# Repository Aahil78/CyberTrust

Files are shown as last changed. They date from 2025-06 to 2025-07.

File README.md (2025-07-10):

# CyberTrust
CyberTrust Is A RP2350A Based Security Key, it can be used as a FIDO2 Secure Key for secure authentication and account safety.

Features:
- Custom PCB
- Custom Enclosure
- Based on the RP2350A MCU
- WS2812B RGB LED
- User Presence Button
- USB-A Male Port
- OSH and OSS

## Images
### PCB




### Schematic


### Enclosure/Assembly



## Bill Of Materials

| Comment | Designator | Footprint | LCSC Part # | Quantity | Total Price |
|---|---|---|---|---|---|
| RP2350_60QFN | U1 | RP2350-QFN-60-1EP_7x7_P0.4mm_EP3.4x3.4mm_ThermalVias| C42411118 | 1 | $ 1.65 |
| 4.7u | C10, C6, C7, C9 | 0402 | C23733 | 4 | $ 0.26 |
| 15p | C3, C4 | 0402 | C1548 | 2 | $ 0.1 |
| 33 | R5 | 0402 | C25105 | 1 | $ 0.06 |
| USB3_A | J1 | USB3_A_Plug_Wuerth_692112030100_Horizontal | C7527682 | 1 | $ 0.44 |
| WS2812B | D1 | LED_WS2812B_PLCC4_5.0x5.0mm_P3.2mm | C2761795 | 1 | $ 0.41 |
| 1k | R2, R4, R6 | 0402 | C11702 | 3 | $ 0.06 |
| NCP1117-3.3_SOT223| U2 | SOT-223-3_TabPin2 | C26537 | 1 | $ 1.31 |
| 3.3u | L1 | L_pol_2016 | C42411119 | 1 | $ 1.29 |
| 0 | R10 | 0402 | C17168 | 1 | $ 0.06 |
| W25Q128JVS | U3 | SOIC-8_5.23x5.23mm_P1.27mm | C97521 | 1 | $ 0.76 |
| SW_Push | SW3 | SW_Push_SPST_NO_Alps_SKRK | C115357 | 1 | $ 0.63 |
| 330Ω | R3 | 0805 | C17630 | 1 | $ 0.19 |
| 10u | C1, C19, C5 | 0805 | C15850 | 3 | $ 0.22 |
| 100n | C11, C12, C13, C14, C15, C16, C17, C18, C2, C8 | 0402 | C1525 | 10 | $ 0.12 |
| SW_Push | SW1, SW2 | SW_Push_1P1T_NO_Vertical_Wuerth_434133025816 | C5504987 | 2 | $ 1.86 |
| ABM8-272-T3 | Y1 | Crystal_SMD_3225-4Pin_3.2x2.5mm | C20625731 | 1 | $ 0.37 |
| 27 | R7, R8 | 0402 | C25100 | 2 | $ 0.06 |

## Additional Stuff
- PCB - $4.2
- Enclosure (3D Printed Case and Top) - Bottom: $10.89, Top(Transparent Resin): $14.40
- Screws - $0.132
- PCBA Costs - $60.66 (I need to solder RGBs, MOQ: 5, Total Cost: $0.41)

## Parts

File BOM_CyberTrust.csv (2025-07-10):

Comment | Designator | Footprint | LCSC Part # | Quantity | Total Price
RP2350_60QFN | U1 | RP2350-QFN-60-1EP_7x7_P0.4mm_EP3.4x3.4mm_ThermalVias | C42411118 | 1 | $1.65
4.7u | C10, C6, C7, C9 | 402 | C23733 | 4 | $0.26
15p | C3, C4 | 402 | C1548 | 2 | $0.10
33 | R5 | 402 | C25105 | 1 | $0.06
USB3_A | J1 | USB3_A_Plug_Wuerth_692112030100_Horizontal | C7527682 | 1 | $0.44
WS2812B | D1 | LED_WS2812B_PLCC4_5.0x5.0mm_P3.2mm | C2761795 | 1 | $0.41
1k | R2, R4, R6 | 402 | C11702 | 3 | $0.06
NCP1117-3.3_SOT223 | U2 | SOT-223-3_TabPin2 | C26537 | 1 | $1.31
3.3u | L1 | L_pol_2016 | C42411119 | 1 | $1.29
0 | R10 | 402 | C17168 | 1 | $0.06
W25Q128JVS | U3 | SOIC-8_5.23x5.23mm_P1.27mm | C97521 | 1 | $0.76
SW_Push | SW3 | SW_Push_SPST_NO_Alps_SKRK | C115357 | 1 | $0.63
330Ω | R3 | 805 | C17630 | 1 | $0.19
10u | C1, C19, C5 | 805 | C15850 | 3 | $0.22
100n | C11, C12, C13, C14, C15, C16, C17, C18, C2, C8 | 402 | C1525 | 10 | $0.12
SW_Push | SW1, SW2 | SW_Push_1P1T_NO_Vertical_Wuerth_434133025816 | C5504987 | 2 | $1.86
ABM8-272-T3 | Y1 | Crystal_SMD_3225-4Pin_3.2x2.5mm | C20625731 | 1 | $0.37
27 | R7, R8 | 402 | C25100 | 2 | $0.06
Additonal Stuff:
PCB - $4.2
Enclosure (3D Printed Case and Top) - Bottom: $10.89, Top(Transparent Resin): $14.40
Screws - $0.132
PCBA Costs - $60.66 (I need to solder RGBs, MOQ: 5, Total Cost: $0.41)

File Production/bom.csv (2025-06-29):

Designator | Footprint | Quantity | Value | LCSC Part #
C1, C19, C5 | 0805 | 3 | 10u
C10, C6, C7, C9 | 0402 | 4 | 4.7u
C11, C12, C13, C14, C15, C16, C17, C18, C2, C8 | 0402 | 10 | 100n
C3, C4 | 0402 | 2 | 15p
D1 | LED_WS2812B_PLCC4_5.0x5.0mm_P3.2mm | 1 | WS2812B
H1, H2, H3, H4 | MountingHole_2.7mm_M2.5 | 4 | MountingHole
J1 | USB3_A_Plug_Wuerth_692112030100_Horizontal | 1 | USB3_A
L1 | L_pol_2016 | 1 | 3.3u
R1, R9 | 0402 | 2 | DNF
R10 | 0402 | 1 | 0
R2, R4, R6 | 0402 | 3 | 1k
R3 | 0805 | 1 | 330Ω
R5 | 0402 | 1 | 33
R7, R8 | 0402 | 2 | 27
SW1, SW2 | SW_Push_1P1T_NO_Vertical_Wuerth_434133025816 | 2 | SW_Push
SW3 | SW_Push_SPST_NO_Alps_SKRK | 1 | SW_Push
U1 | RP2350-QFN-60-1EP_7x7_P0.4mm_EP3.4x3.4mm_ThermalVias | 1 | RP2350_60QFN
U2 | SOT-223-3_TabPin2 | 1 | NCP1117-3.3_SOT223
U3 | SOIC-8_5.23x5.23mm_P1.27mm | 1 | W25Q128JVS
Y1 | Crystal_SMD_3225-4Pin_3.2x2.5mm | 1 | ABM8-272-T3

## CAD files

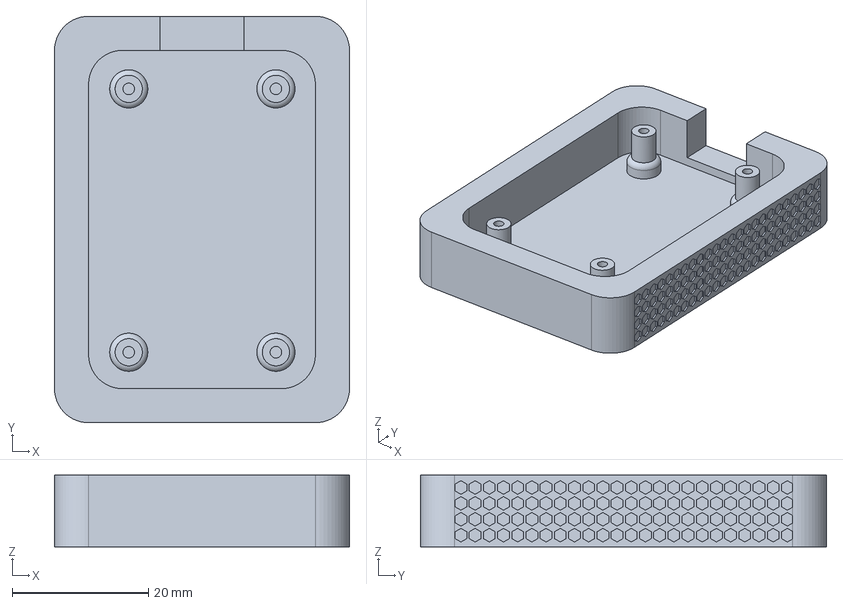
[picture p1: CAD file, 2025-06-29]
3D Models/Bottom.step
43.3 x 59.7 x 10.5 mm

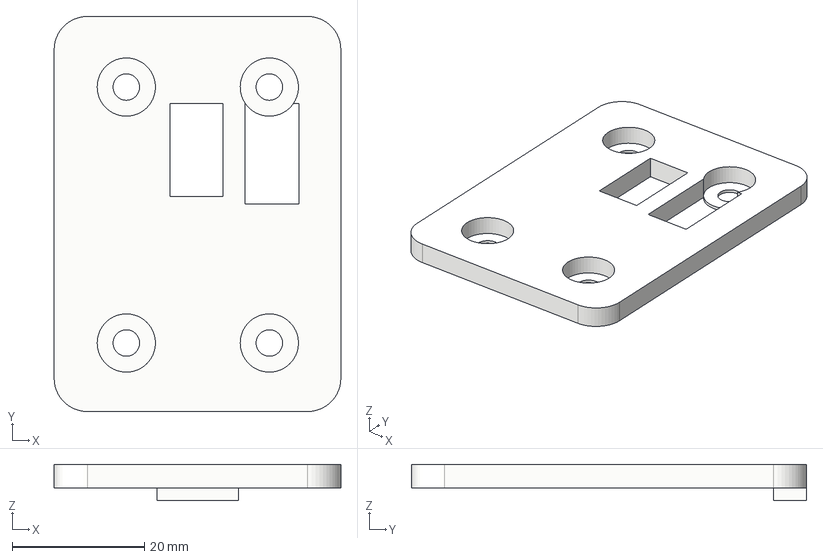
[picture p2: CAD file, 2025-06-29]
3D Models/Top.step
43.3 x 59.7 x 5.50 mm

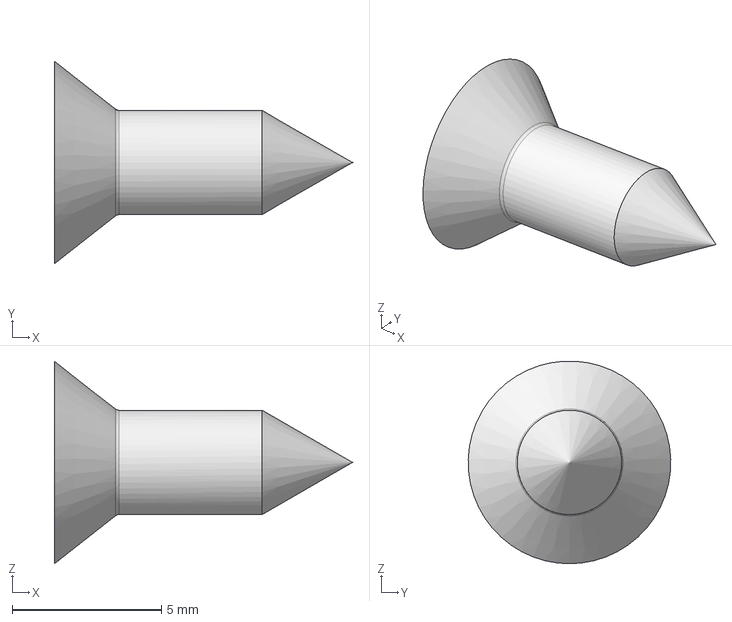
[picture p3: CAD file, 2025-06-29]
3D Models/Screws.step
10.0 x 6.80 x 6.79 mm

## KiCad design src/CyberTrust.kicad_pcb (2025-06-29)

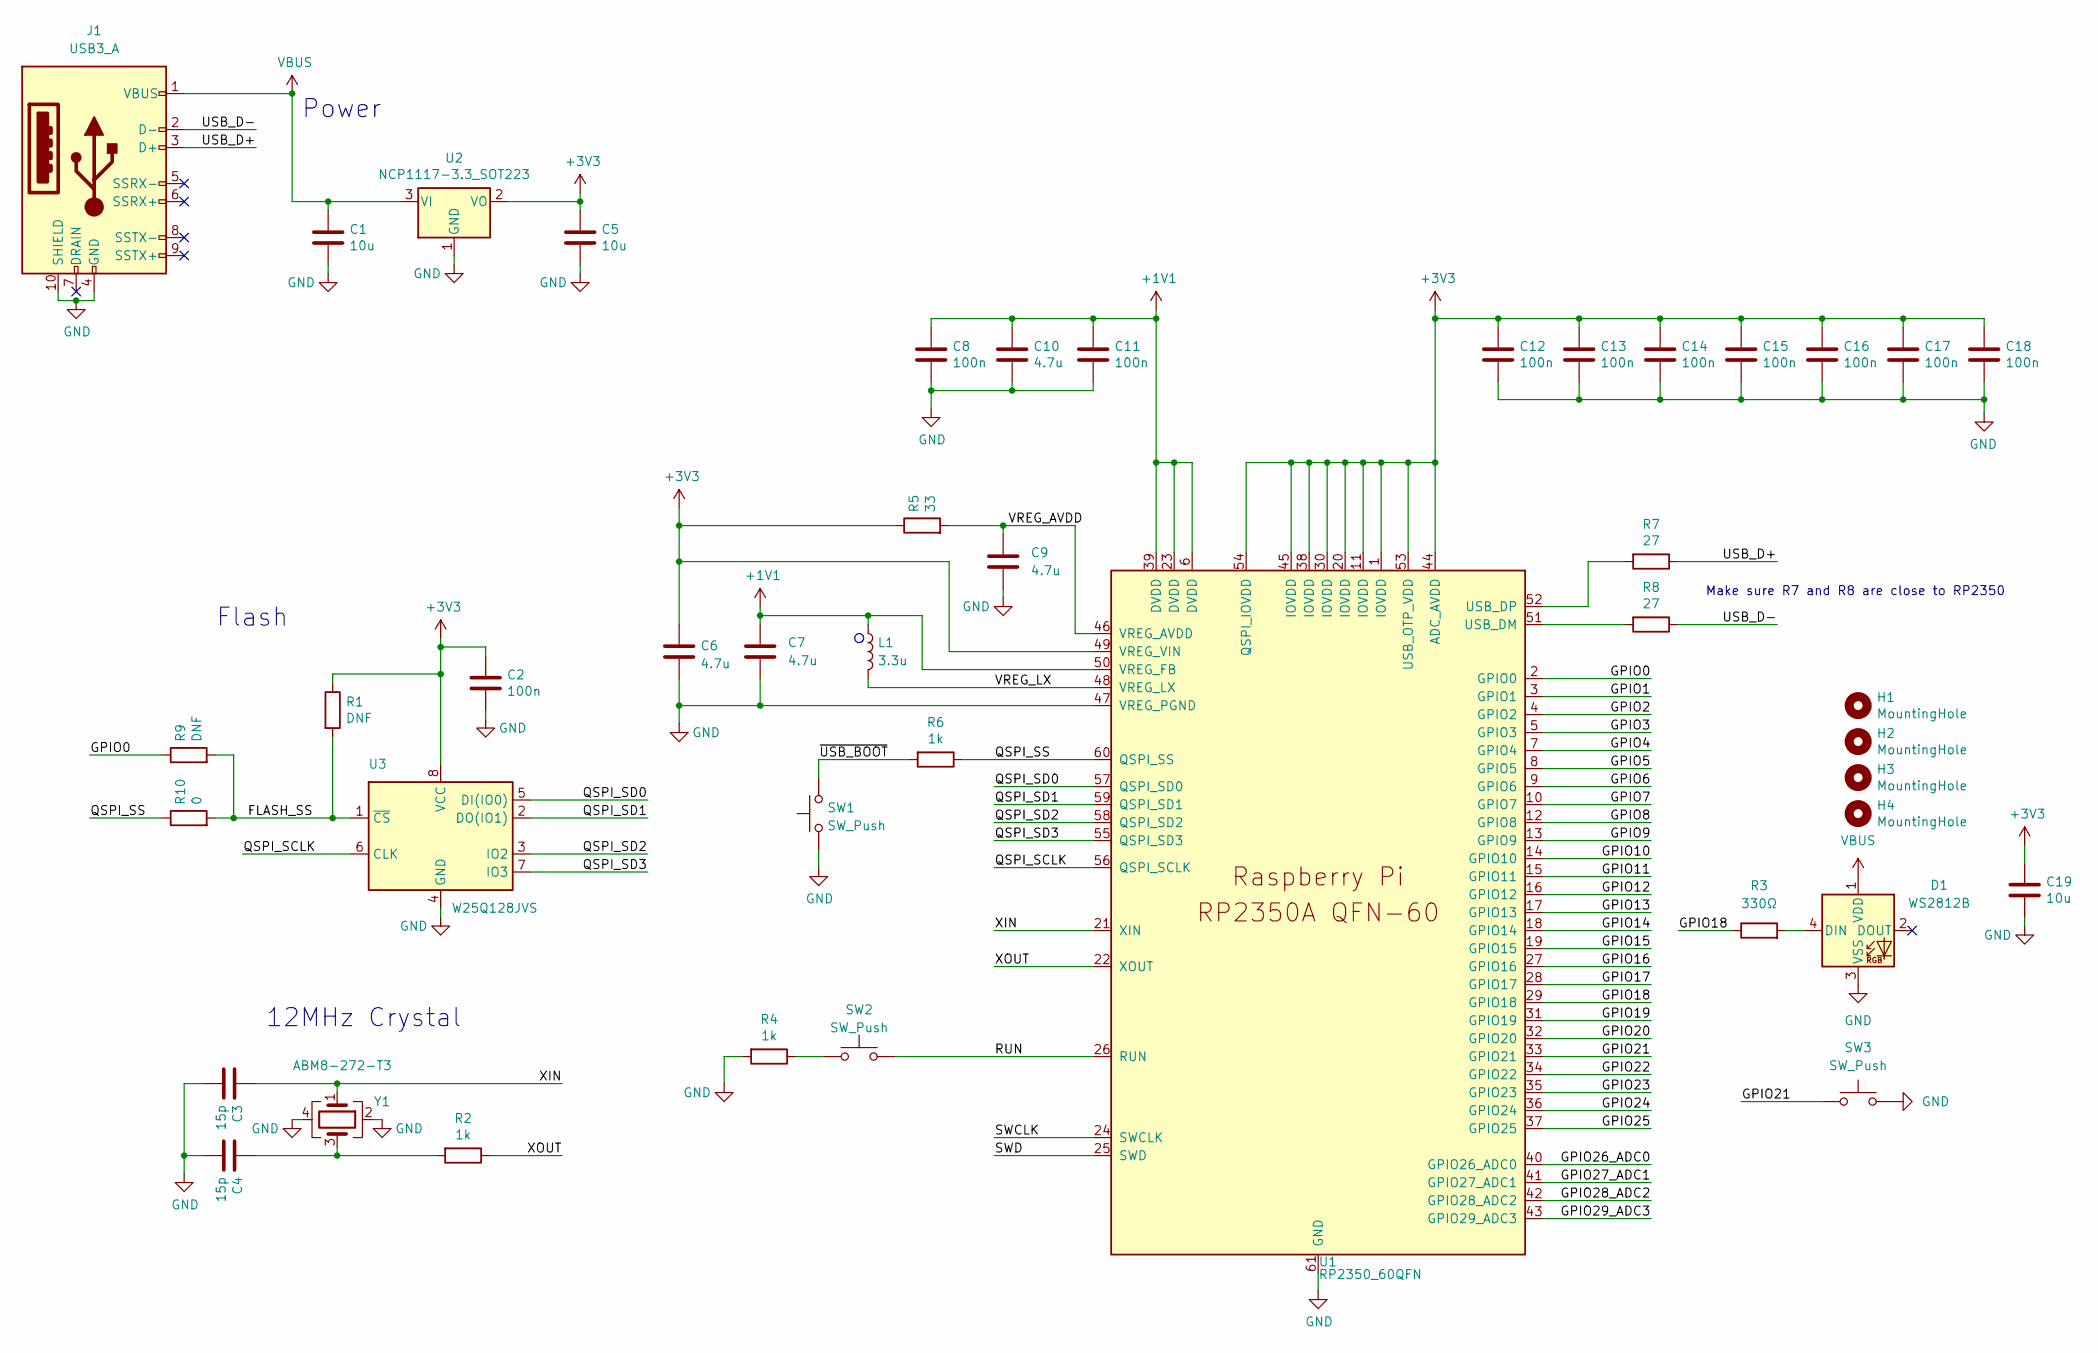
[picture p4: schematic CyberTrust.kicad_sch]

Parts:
C1, C5, C19: 10u; C_0805_2012Metric
C2, C8, C11, C12, C13, C14, C15, C16, C17, C18: 100n; C_0402_1005Metric
C3, C4: 15p; C_0402_1005Metric
C6, C7: 4.7u; C_0402_1005Metric_small_pads
C9, C10: 4.7u; C_0402_1005Metric
D1: WS2812B; LED_WS2812B_PLCC4_5.0x5.0mm_P3.2mm
H1, H2, H3, H4: MountingHole; MountingHole_2.7mm_M2.5
J1: USB3_A; USB3_A_Plug_Wuerth_692112030100_Horizontal
L1: 3.3u; L_pol_2016
R1, R9: DNF; R_0402_1005Metric
R2, R4, R6: 1k; R_0402_1005Metric
R3: 330Ω; R_0805_2012Metric_Pad1.20x1.40mm_HandSolder
R5: 33; R_0402_1005Metric
R7, R8: 27; R_0402_1005Metric
R10: 0; R_0402_1005Metric
SW1, SW2: SW_Push; SW_Push_1P1T_NO_Vertical_Wuerth_434133025816
SW3: SW_Push; SW_Push_SPST_NO_Alps_SKRK
U1: RP2350_60QFN; RP2350-QFN-60-1EP_7x7_P0.4mm_EP3.4x3.4mm_ThermalVias
U2: NCP1117-3.3_SOT223; SOT-223-3_TabPin2
U3: W25Q128JVS; SOIC-8_5.23x5.23mm_P1.27mm
Y1: ABM8-272-T3; Crystal_SMD_3225-4Pin_3.2x2.5mm

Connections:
+1V1: C7.1, C8.1, C10.1, C11.1, L1.1, U1.6 (DVDD), U1.23 (DVDD), U1.39 (DVDD), U1.50 (VREG_FB)
+3V3: C2.1, C5.1, C6.1, C12.1, C13.1, C14.1, C15.1, C16.1, C17.1, C18.1, C19.1, R1.1, R5.1, U1.1 (IOVDD), U1.11 (IOVDD), U1.20 (IOVDD), U1.30 (IOVDD), U1.38 (IOVDD), U1.44 (ADC_AVDD), U1.45 (IOVDD), U1.49 (VREG_VIN), U1.53 (USB_OTP_VDD), U1.54 (QSPI_IOVDD), U2.2 (VO), U3.8 (VCC)
/FLASH_SS: R1.2, R9.2, R10.2, U3.1 (~CS)
/GPIO0: R9.1, U1.2 (GPIO0)
/GPIO1: U1.3 (GPIO1)
/GPIO2: U1.4 (GPIO2)
/GPIO3: U1.5 (GPIO3)
/GPIO4: U1.7 (GPIO4)
/GPIO5: U1.8 (GPIO5)
/GPIO6: U1.9 (GPIO6)
/GPIO7: U1.10 (GPIO7)
/GPIO8: U1.12 (GPIO8)
/GPIO9: U1.13 (GPIO9)
/GPIO10: U1.14 (GPIO10)
/GPIO11: U1.15 (GPIO11)
/GPIO12: U1.16 (GPIO12)
/GPIO13: U1.17 (GPIO13)
/GPIO14: U1.18 (GPIO14)
/GPIO15: U1.19 (GPIO15)
/GPIO16: U1.27 (GPIO16)
/GPIO17: U1.28 (GPIO17)
/GPIO18: R3.1, U1.29 (GPIO18)
/GPIO19: U1.31 (GPIO19)
/GPIO20: U1.32 (GPIO20)
/GPIO21: SW3.1, U1.33 (GPIO21)
/GPIO22: U1.34 (GPIO22)
/GPIO23: U1.35 (GPIO23)
/GPIO24: U1.36 (GPIO24)
/GPIO25: U1.37 (GPIO25)
/GPIO26_ADC0: U1.40 (GPIO26_ADC0)
/GPIO27_ADC1: U1.41 (GPIO27_ADC1)
/GPIO28_ADC2: U1.42 (GPIO28_ADC2)
/GPIO29_ADC3: U1.43 (GPIO29_ADC3)
/QSPI_SCLK: U1.56 (QSPI_SCLK), U3.6 (CLK)
/QSPI_SD0: U1.57 (QSPI_SD0), U3.5 (DI(IO0))
/QSPI_SD1: U1.59 (QSPI_SD1), U3.2 (DO(IO1))
/QSPI_SD2: U1.58 (QSPI_SD2), U3.3 (IO2)
/QSPI_SD3: U1.55 (QSPI_SD3), U3.7 (IO3)
/QSPI_SS: R6.1, R10.1, U1.60 (QSPI_SS)
/RUN: SW2.2, U1.26 (RUN)
/SWCLK: U1.24 (SWCLK)
/SWD: U1.25 (SWD)
/USB_D+: J1.3 (D+), R7.1
/USB_D-: J1.2 (D-), R8.1
/VREG_AVDD: C9.1, R5.2, U1.46 (VREG_AVDD)
/VREG_LX: L1.2, U1.48 (VREG_LX)
/XIN: C3.1, U1.21 (XIN), Y1.1
/XOUT: R2.1, U1.22 (XOUT)
/~USB_BOOT: R6.2, SW1.2
GND: C1.2, C2.2, C3.2, C4.2, C5.2, C6.2, C7.2, C8.2, C9.2, C10.2, C11.2, C12.2, C13.2, C14.2, C15.2, C16.2, C17.2, C18.2, C19.2, D1.3 (VSS), J1.4 (GND), J1.10 (SHIELD), R4.2, SW1.1, SW3.2, U1.47 (VREG_PGND), U1.61 (GND), U2.1 (GND), U3.4 (GND), Y1.2, Y1.4
unnamed: C4.1, R2.2, Y1.3
unnamed: D1.4 (DIN), R3.2
unnamed: R4.1, SW2.1
unnamed: R8.2, U1.51 (USB_DM)
unnamed: R7.2, U1.52 (USB_DP)
VBUS: C1.1, D1.1 (VDD), J1.1 (VBUS), U2.3 (VI)

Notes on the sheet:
Flash
Make sure R7 and R8 are close to RP2350
12MHz Crystal
Power

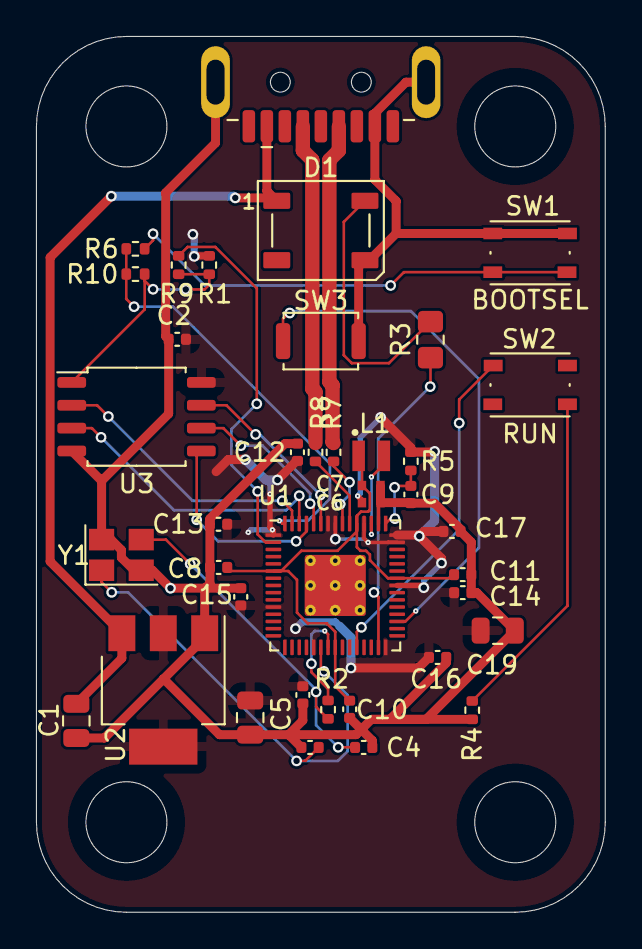
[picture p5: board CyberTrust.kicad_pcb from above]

Board: 2 copper layers, 31.6 x 48.7 mm, 43 parts (0 on the bottom side), 27 nets.

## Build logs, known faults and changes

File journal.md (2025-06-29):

---
title: "CyberTrust"
author: "Aahil"
description: "A RP2350A Based Hardware Security Key with a keypad add-on, RGB LED, and idk other things!"
created_at: "2025-06-25"
---

**Total time worked for designing: 80 hours**

## June 25th: Research, Schematic, and PCB Layout
Hi! I'm back with a new project, while my keyboard is being reviewed and other projects are stuck in shipping, I decided to make another project! I've seen lots of ppl getting their accounts hacked, especially my parents, so I decided to make a Security Key USB! This way, accounts can stay secure, I'll learn dev-board design - sorta - (2nd Dev Board I have ever designed, 1st was a ESP32-S3 embedded in a High Speed Competition Level Line Following Robot). So today I researched a lot, made my schematic, and made the layout of my PCB. Now I need to assign netclasses, do the routing, and route the firmware. Oh and I also need to make the case and modular keypad.






I made the schematic based off of Raspberry Pi's design files to minimize errors. Rlly excited for this bc my old Microsoft Account got hacked and I lost minecraft :(

**Total time spent: 3.5hrs**

## June 25th - Log 2: Done with the routing
Damn that was fast, I'm done with all the routing rn. I didnt add the connector yet for the keypad becuase I think that will need another MCU on the keypad, I'll see what to do for the keypad and then do that too, I think this is gonna be done by today becuase I'm already done with 99% of the PCB and Schematic lol.




Edit/Update: I ain't adding the keypad for now because I want this to be user friendly so for now no numpad, sorry!

**Total time spent: 55mins**

# June 26th: Making the component models

Damn that took a long time and I didn't even make the case yet, I had to asign all the 3D Models to the PCB so I can make a proper case, for some components I had to make the 3D Models myself! Which took a veryyy long time, now I'll finally start the enclosure in Fusion 260.




**Total time spent: 7hrs**

## June 29th: This dosen't feel like a hobby it feels like child labor

I am almost done with my case, I have litarally been working for 3 days straight no sleep, worked over 30 iterations and finaly came to one I like and actually fits the PCBs Screw Holes, I had to modify my PCB to have larger holes because I'm not screwing it in, instead it will go through the parts where I'll screw, and sit on standoffs, everything is one model so no external hardware needed except for Self Tapping screws, why slef tapping? Because I'm screwing them directly into the print, I was also thinking of like maybe a acrylic see through top for the RGB LED, it would look very good. Now I just need to do the finishing touches (I dont get paid enough for this, I'll just be getting $50 which is too low of a budget aghhhhh)








**Total time spent: 3 days straight minus food breaks and other stuff = 67hrs**

## June 29th - Log 2: Done!

The sun is rising as I'm done with the case! Like actually it's sunrise, so I uhh have added all the finishing touches and everything. Everything fits properly and it looks good. But the buttons dont have any caps on them so u need to put ur finger through to press them, now I'll just upload all relevant files and submit in a bit.





**Total time psent: 1-2hrs**
